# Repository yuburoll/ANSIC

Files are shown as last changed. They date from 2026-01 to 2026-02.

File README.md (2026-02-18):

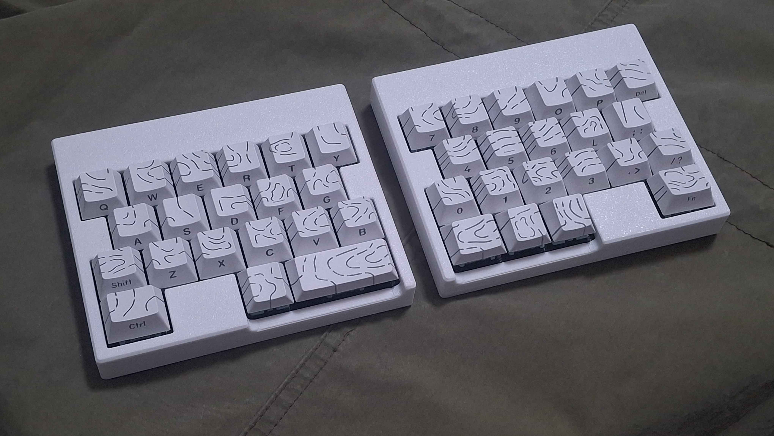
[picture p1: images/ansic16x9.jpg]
ansicImage


[한국어 설명은 여기에서 보실 수 있습니다](README_ko.md)

# ANSIC

uniform row staggered 40~42 key split keyboard under 100x100mm PCB

The name "ansic" is repose in Korean.

## Preparation

- 2x pro micro (Approx. 4-8$)

- 2x ansic PCB Boards (5 boards are 2$ on JLC w/o shipping cost)

- 1x printed case sets, 2 parts total (Approx. 6$ if you buy printed one on JLC. Use braced ones or 2mm ones for 3d print)

- 2x keyboard plates (Approx. 4~12$ which method you use: 3DP, FR4 fab, CNC, laser cut. etc...)

- 2x back plates (Approx. 6~18$ which method you use: 3DP, FR4 fab, CNC, laser cut. etc..)

- 42x diodes (Approx. 1$)

- 20x M2x6 screws, flathead (Approx. 1$)

- 2x PJ320A 1/8(3.5mm) TRRS connector (Approx. 1$)

- 2x 4x4x1.5mm surface mount tact switches (Approx. 1$)

- 1x 1/8(3.5mm) TRRS cable (Approx. 2$, may TRS cable can take the place.)

- 44x MX Hotswap Sockets (Approx. 5$) (or, use soldering version)

- 0~2x Plate Mounted 2u Keyboard Stabilizers (Approx. 1$ when cheap)

- 40~42x MX Keyswitches & Keycaps (Maybe this cost varies too much. 15$ on average)

Approx. 49-73$(w/o shipping cost) needed to build one.

for wireless build, you may additionally need:

- 2x "Wireless" promicro (eg. nrf52840)

- 2x 12c02 slide switch (very fragile, so handle with caution)

- 2x printed power switch part

- 2x xx2030 Li-po battery (eg. 902030) and socket(in 1.25)

## Default Keymap

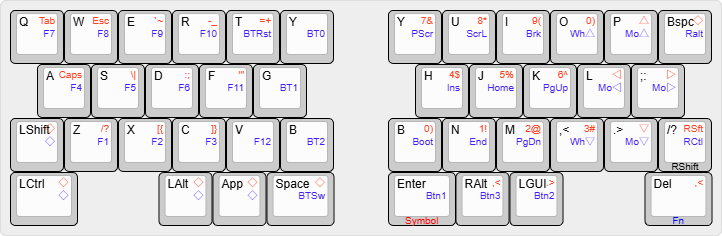
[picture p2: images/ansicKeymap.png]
ansicKeymap


Holding the key triggers front legend.

There are two more layers - Symbol, Fn - which can be noticed by the color legends. ◇ Means Transparent; which uses base keymap.

## Build Guides

work in progress. sorry! I uploaded images for buildguide at [images](images) folder.

also you may refer to the pictures below:

#### Wired

**You may flash the firmware first before the build.** It's hard to make dfu mode after the build.

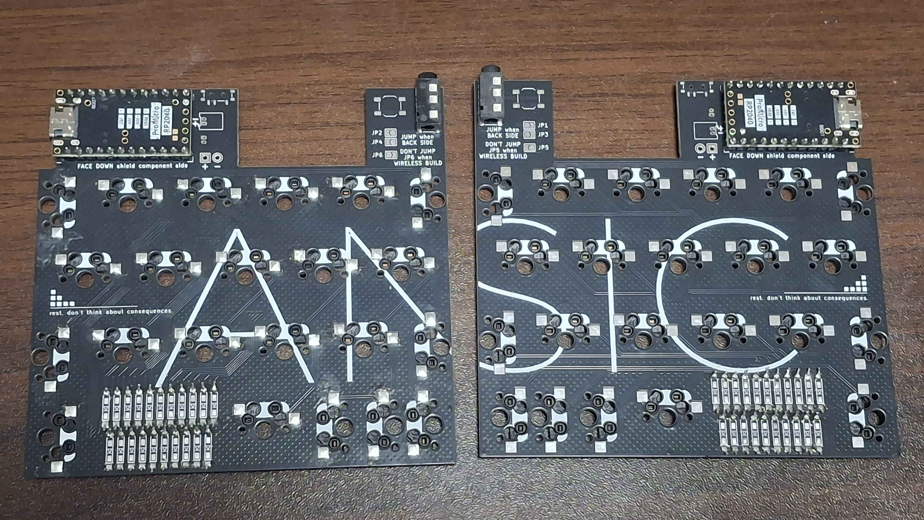
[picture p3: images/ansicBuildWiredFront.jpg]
WiredFront


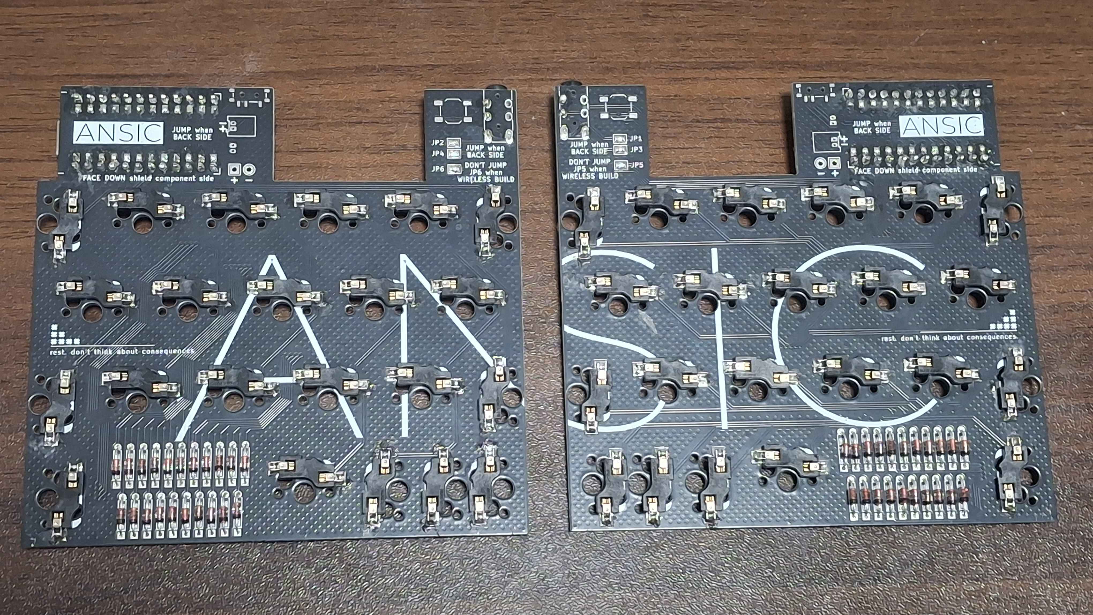
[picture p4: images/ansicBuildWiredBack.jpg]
WiredBack


#### Wireless

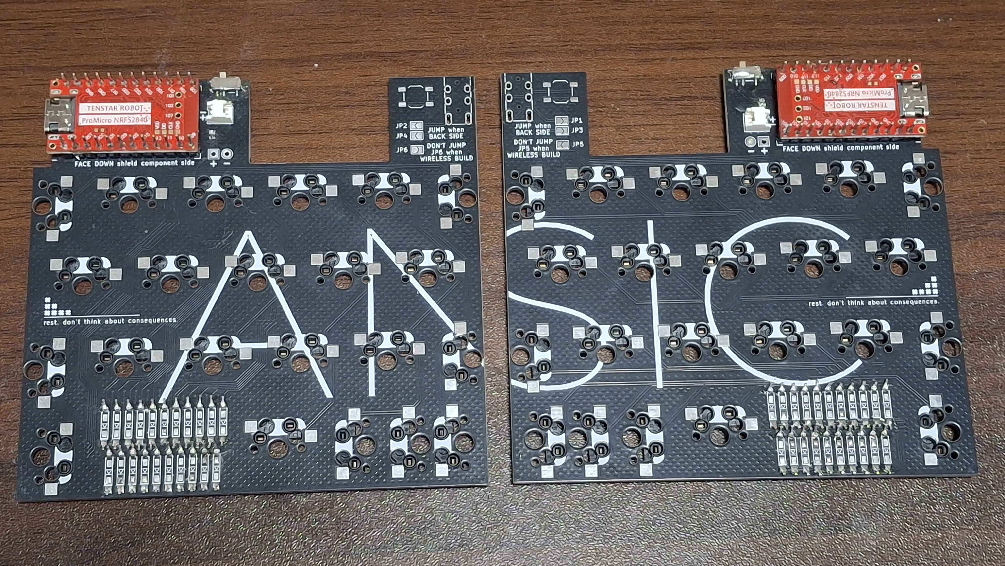
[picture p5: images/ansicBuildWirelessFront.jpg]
WirelessFront


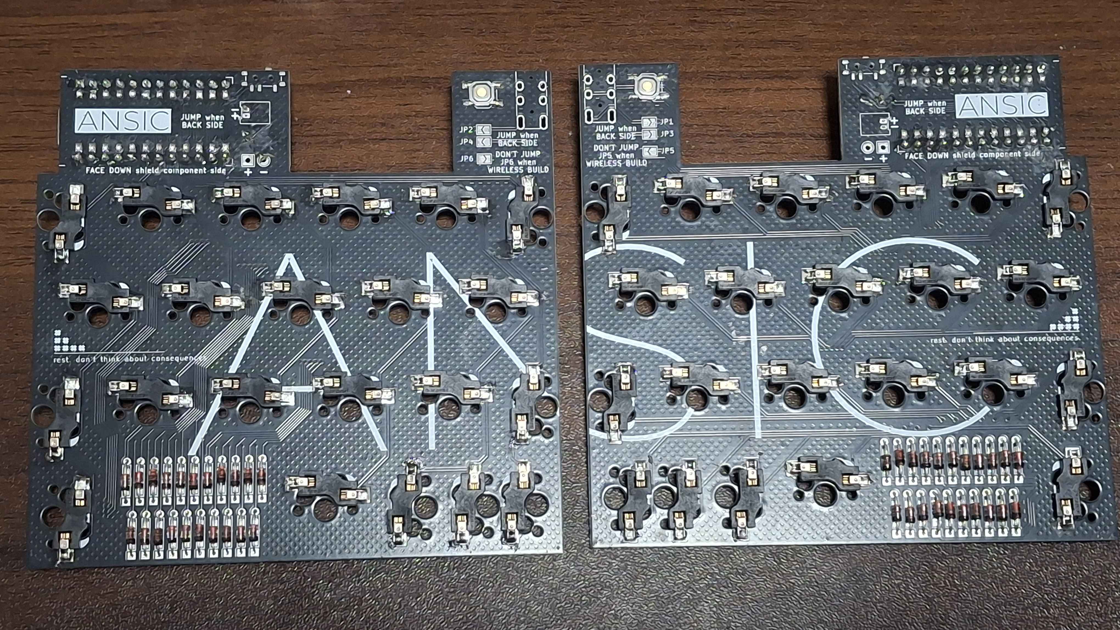
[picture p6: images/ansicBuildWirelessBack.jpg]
WirelessBack


## Note

On released version, they have merged thumb cluster based on SW21(outside thumb cluster).

(prototype) tagged versions are legacy file, which have merged thumb cluster based on SW20(middle thumb cluster). only the gerbers before Jan. 30, 2026 have those old schema.

Both Wired and Wireless version works well: proved by my two builds.

## Licenses

all codes follow MIT license.

all designs and the hardware board follow CC BY-SA 4.0 license.

If you want to make a commercial product, it would be appreciated if you sponsor some bucks for me.

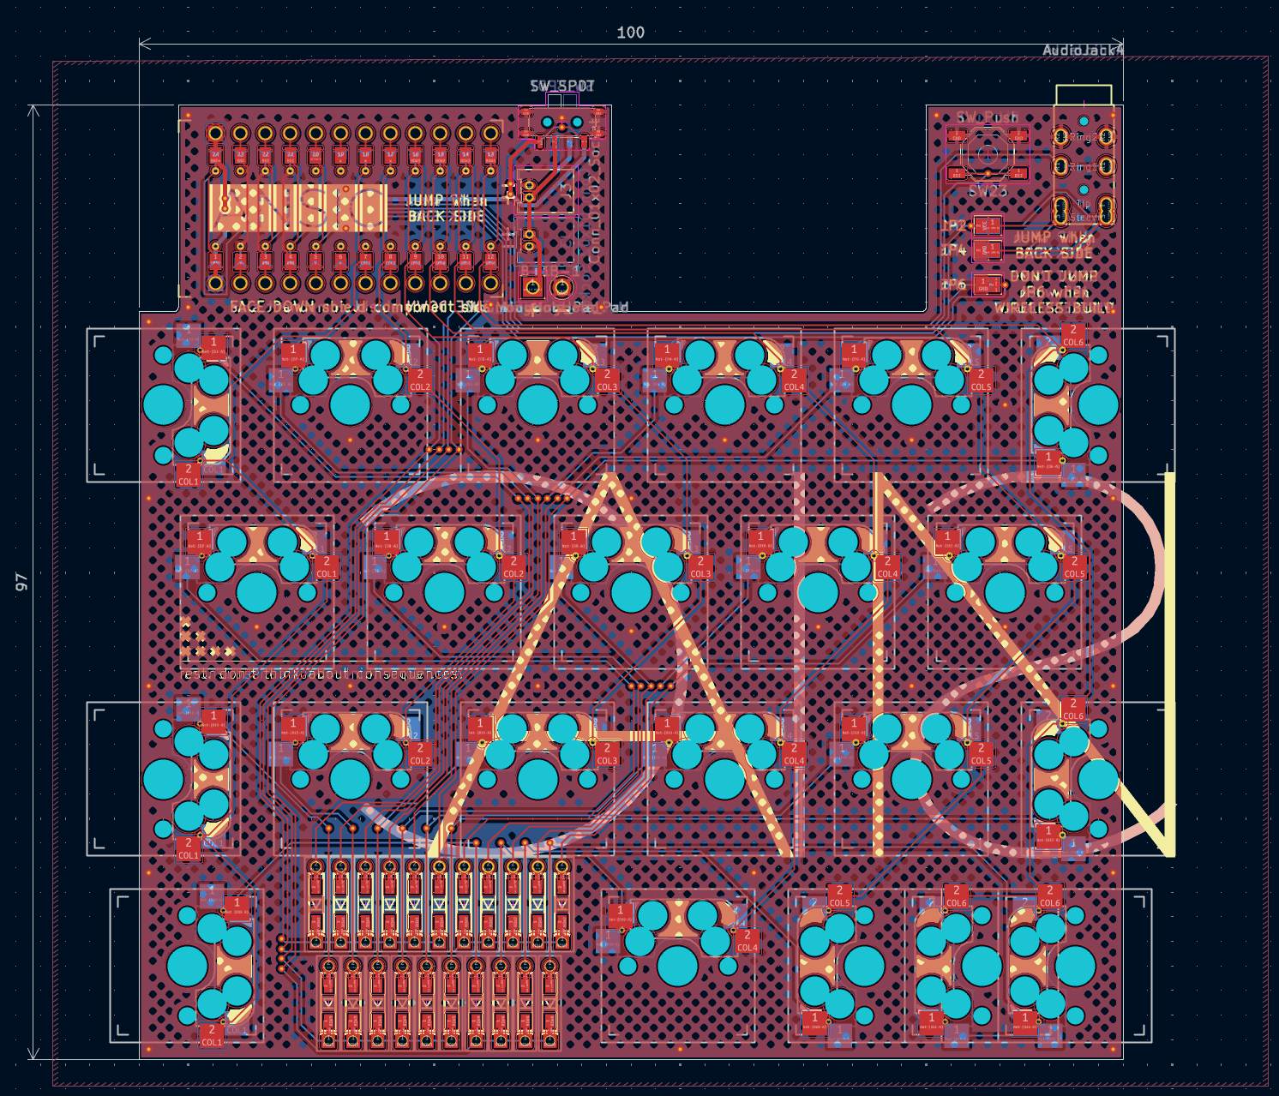
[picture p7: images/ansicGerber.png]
ansicGerber


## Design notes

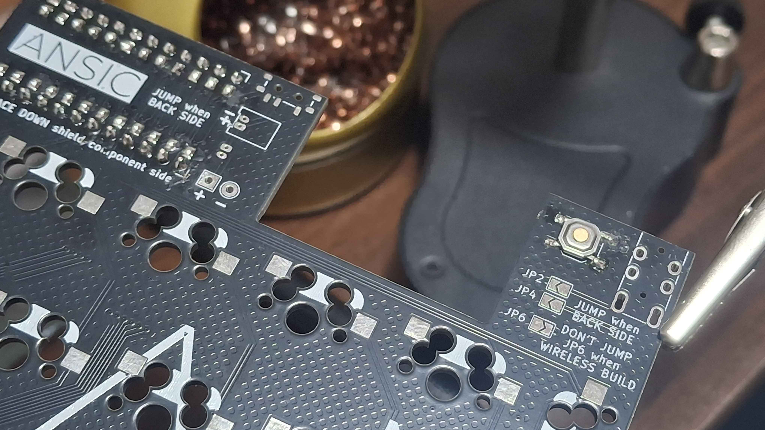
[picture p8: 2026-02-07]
images/ansicResetButton.jpg

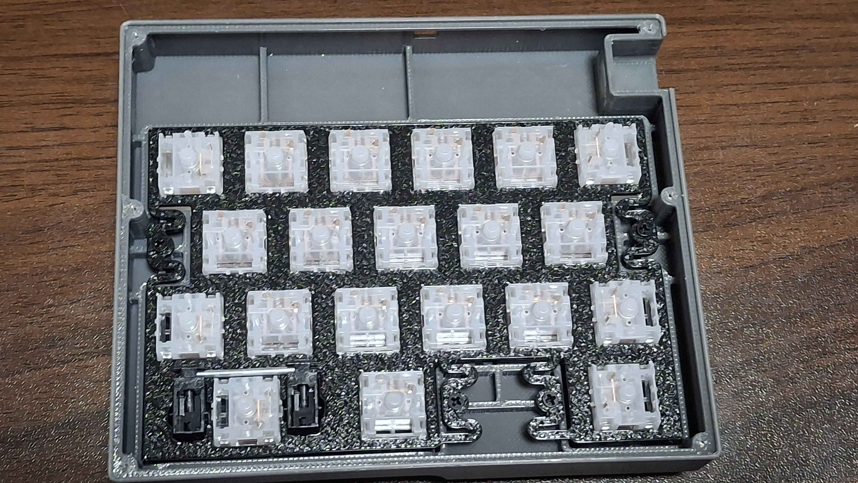
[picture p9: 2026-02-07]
images/ansicOrientation2.jpg

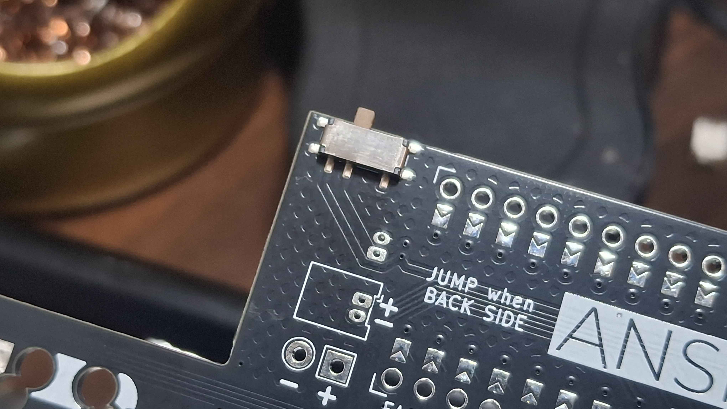
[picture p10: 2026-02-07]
images/ansicWirelessSwitch1.jpg

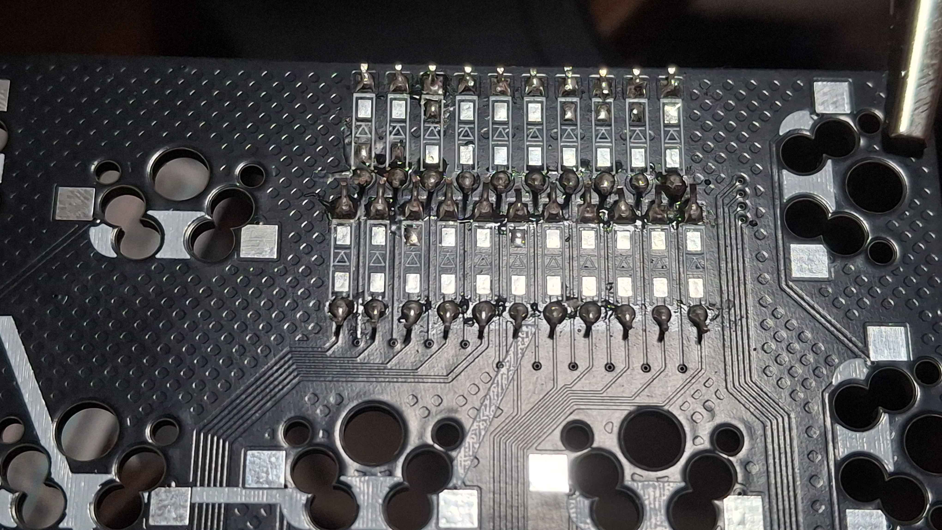
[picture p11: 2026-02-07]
images/ansicDiodes6.jpg

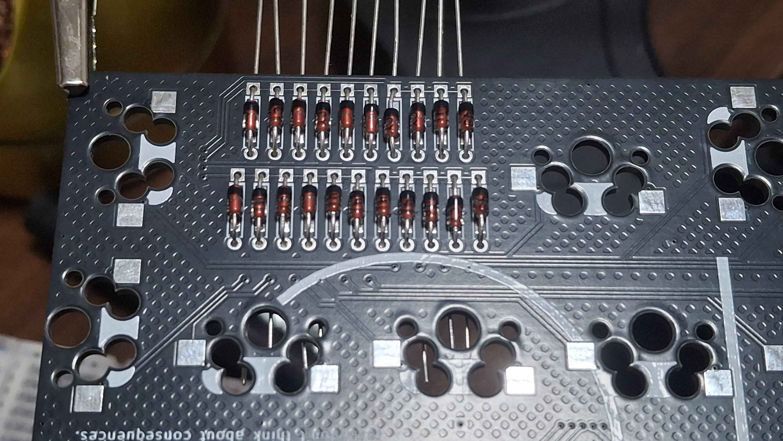
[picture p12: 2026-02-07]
images/ansicDiodes4.jpg

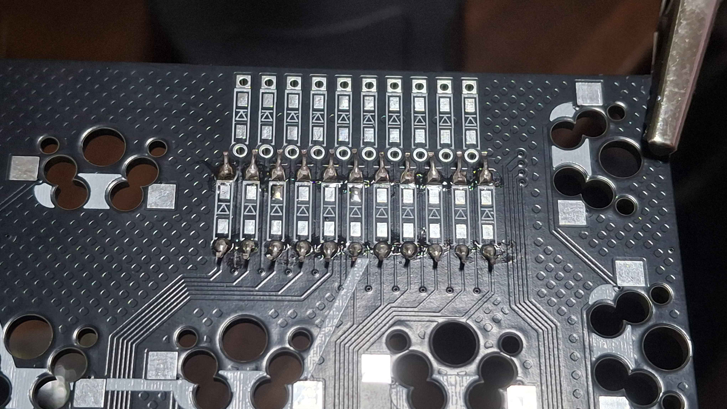
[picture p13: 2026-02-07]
images/ansicDiodes3.jpg

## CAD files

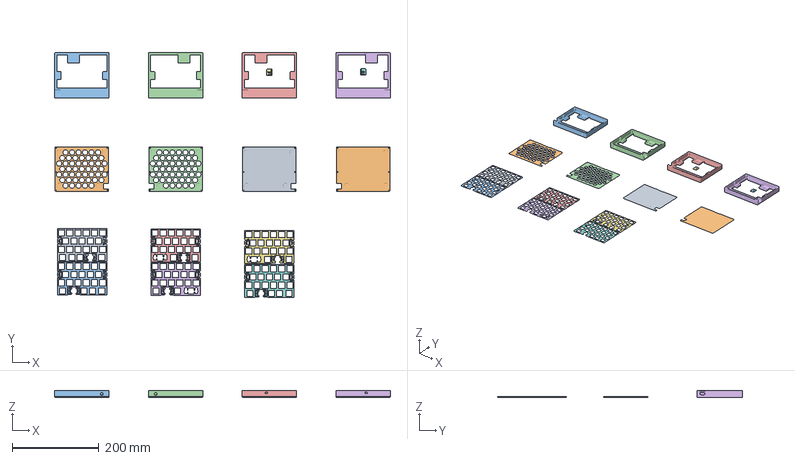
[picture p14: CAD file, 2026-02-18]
case/3mf/ansic2mm.3mf
774.0 x 564.9 x 15.5 mm
ansicPlate21.stl x 3
ansicBackMesh.stl x 2
ansicPlate20.stl x 3
ansicBack.stl x 2
ansicCase2mmWiredFDMBridgeL.stl
ansicCase2mmWiredFDMBridgeR.stl
ansicCase2mmWirelessFDMBridgeL.stl
ansicCase2mmWirelessFDMBridgeR.stl
ansicCase2mmWirelessSwitchSupport.stl x 2

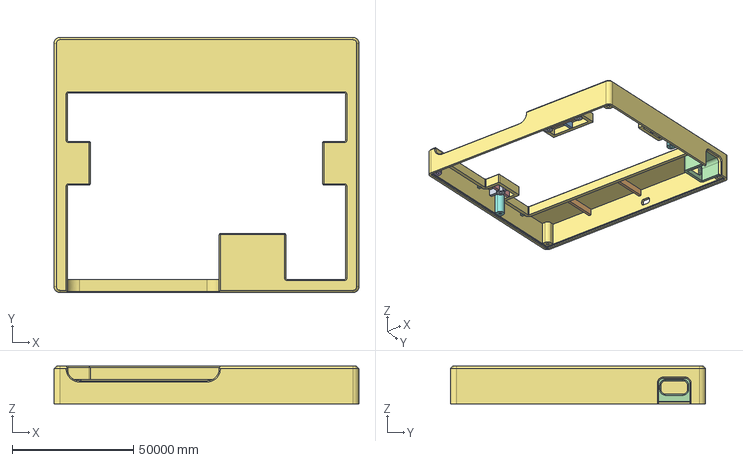
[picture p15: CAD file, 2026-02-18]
case/step/2mmThick/ansicCase2mmWirelessR.stp
126000.0 x 105500.0 x 15500.0 mm

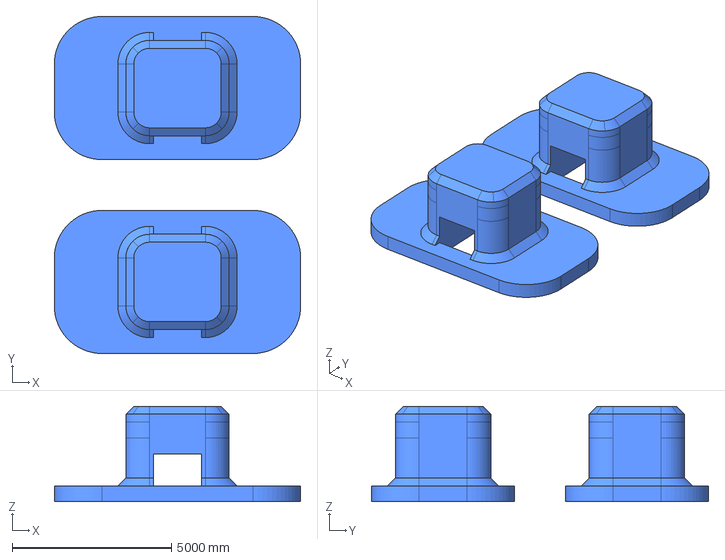
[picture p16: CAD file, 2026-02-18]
case/step/2mmThickSwitch/ansicCase2mmWirelessSwitch.stp
7750.0 x 10596.2 x 3000.0 mm

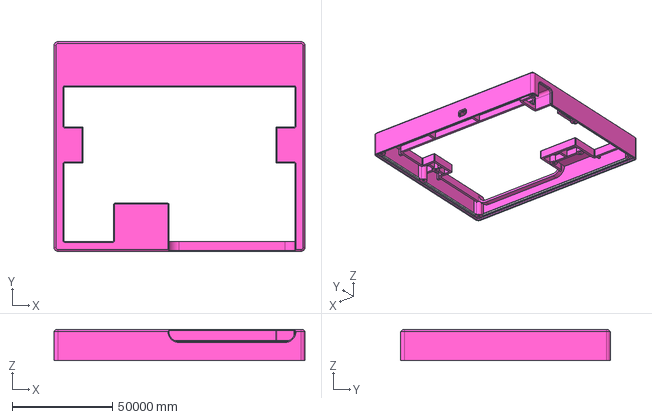
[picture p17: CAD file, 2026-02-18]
case/step/braced-for3DP/ansicCaseBraceWirelessL.stp
125000.0 x 104500.0 x 15500.0 mm

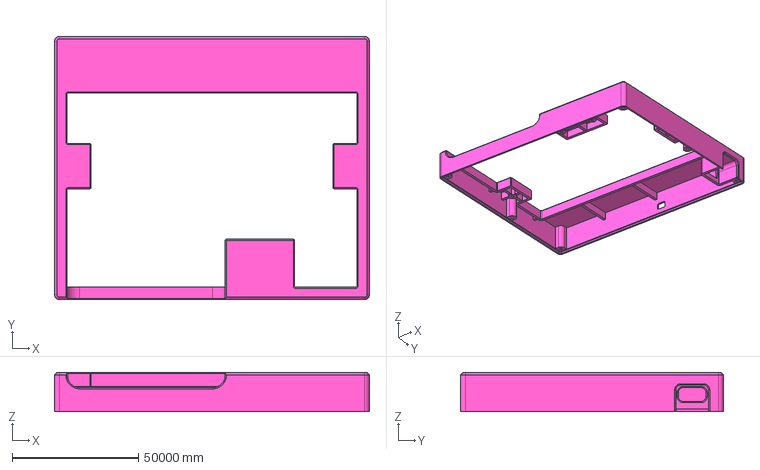
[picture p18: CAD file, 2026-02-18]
case/step/default/ansicCaseDefaultWirelessR.stp
125000.0 x 104500.0 x 15500.0 mm

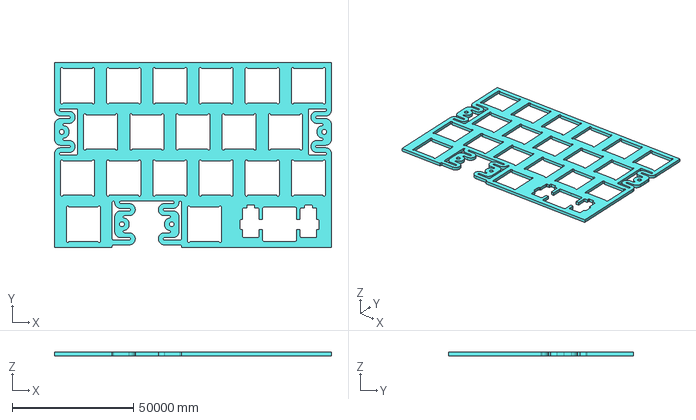
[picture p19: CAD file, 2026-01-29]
case/step/plates/ansicPlate20.stp
114000.0 x 76000.0 x 1500.0 mm

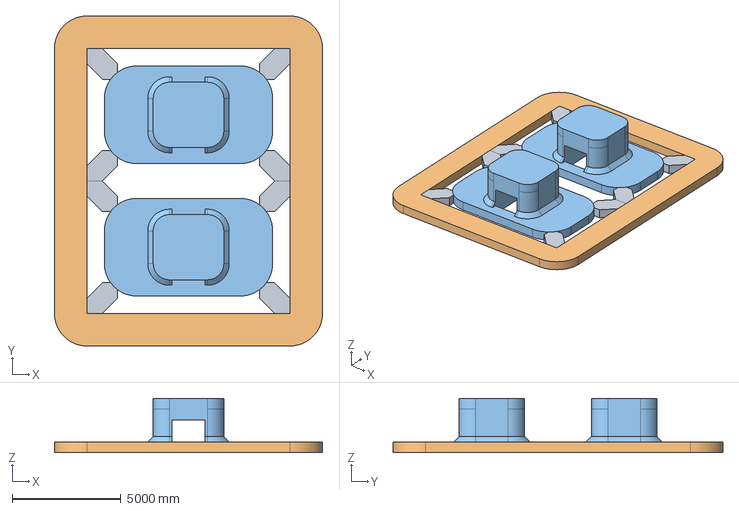
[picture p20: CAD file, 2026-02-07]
case/step/switch/ansicCaseWirelessSwitchSupport.stp
12346.2 x 15192.4 x 2500.0 mm

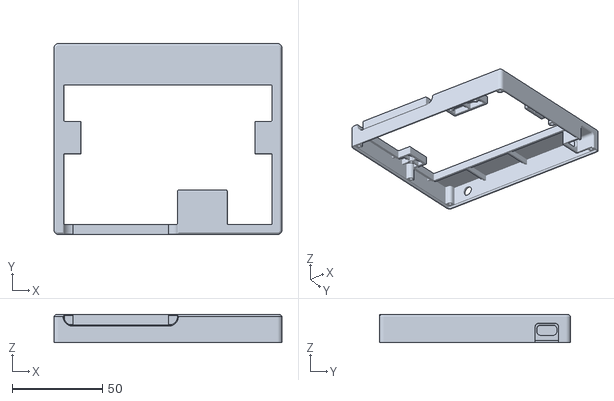
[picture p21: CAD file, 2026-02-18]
case/stl/2mmThickBridged-forFDM/ansicCase2mmWiredFDMBridgeR.stl
126.0 x 105.5 x 15.5

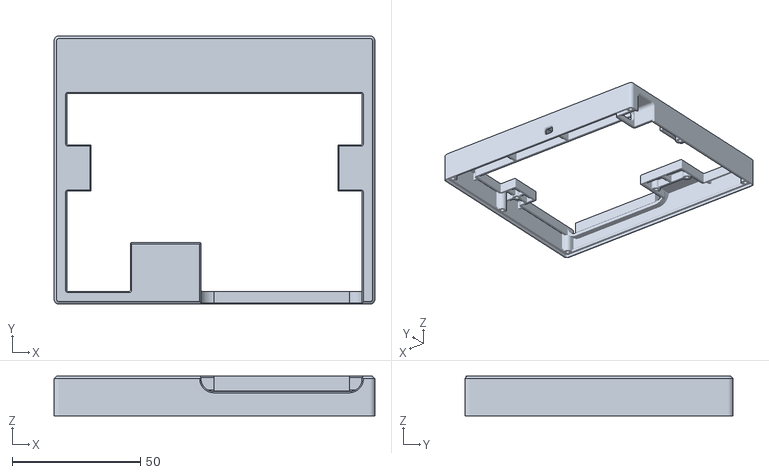
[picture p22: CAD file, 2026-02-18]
case/stl/bridged-forFDM/ansicCaseBraceWirelessFDMBridgeL.stl
125.0 x 104.5 x 15.5

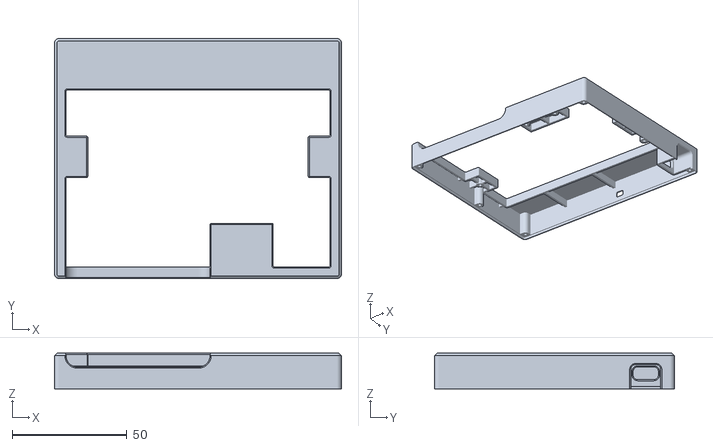
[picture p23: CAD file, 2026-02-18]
case/stl/default/ansicCaseWirelessR.stl
125.0 x 104.5 x 15.5

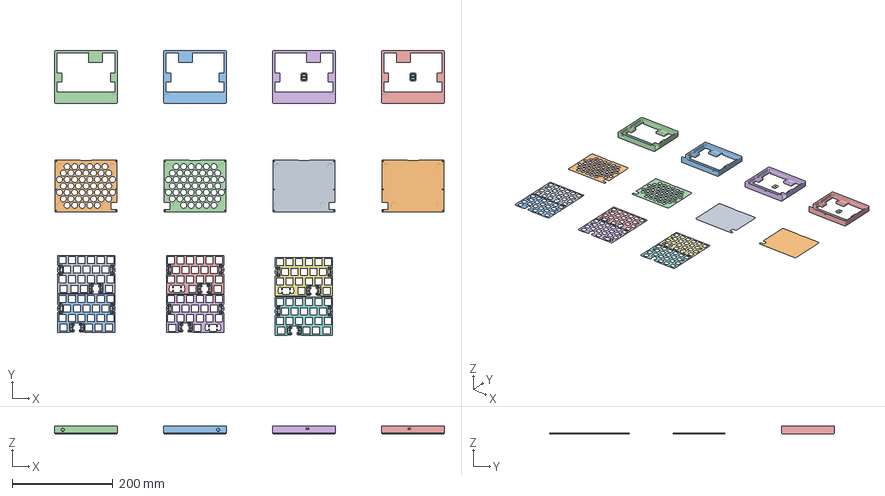
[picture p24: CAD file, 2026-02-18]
case/3mf/ansic.3mf
773.0 x 564.4 x 15.5 mm
ansicPlate21.stl x 3
ansicBackMesh.stl x 2
ansicPlate20.stl x 3
ansicBack.stl x 2
ansicCaseBraceWiredBridgeL.stl
ansicCaseBraceWiredBridgeR.stl
ansicCaseBraceWirelessBridgeL.stl
ansicCaseBraceWirelessBridgeR.stl
ansicCaseWirelessSwitchSupport.stl x 2

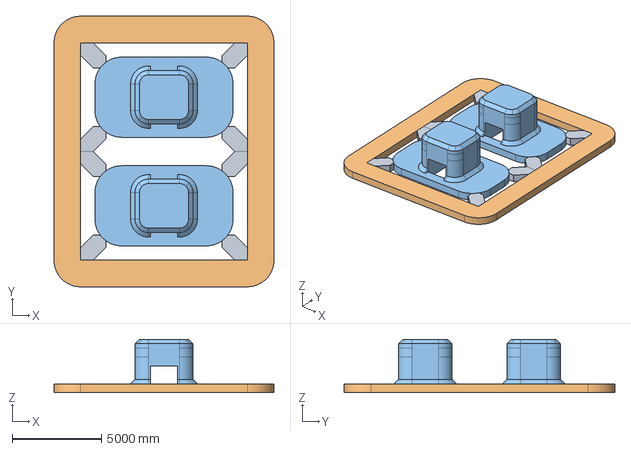
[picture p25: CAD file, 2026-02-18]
case/step/2mmThickSwitch/ansicCase2mmWirelessSwitchSupport.stp
12346.2 x 15192.4 x 3000.0 mm

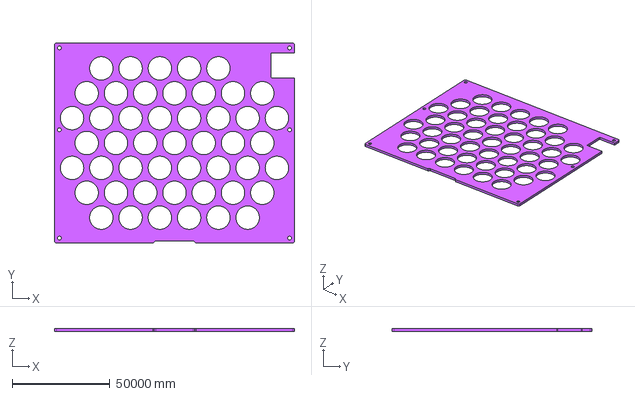
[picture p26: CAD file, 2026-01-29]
case/step/plates/ansicBackMeshR.stp
123000.0 x 102500.0 x 1500.0 mm

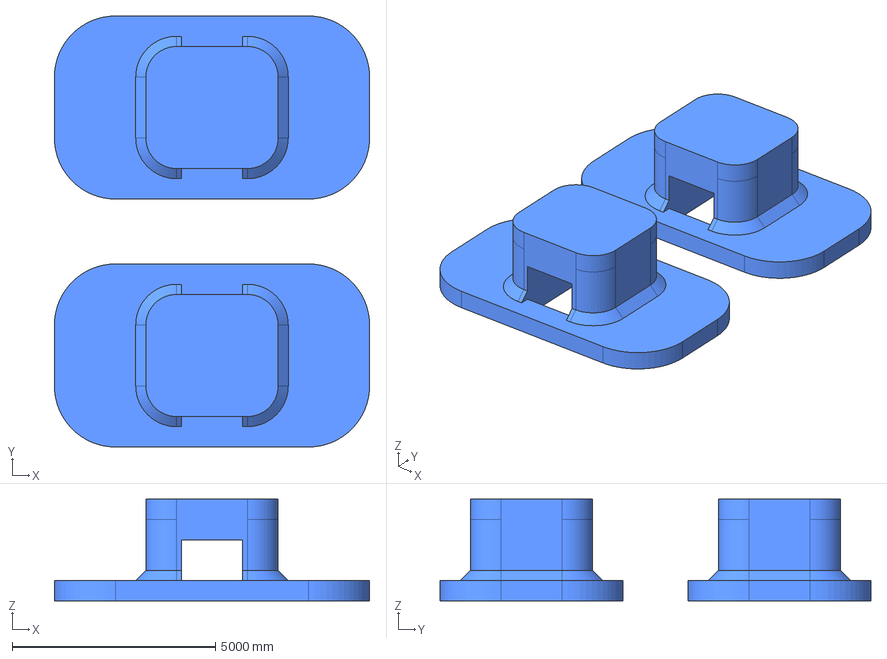
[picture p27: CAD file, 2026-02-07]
case/step/switch/ansicCaseWirelessSwitch.stp
7750.0 x 10596.2 x 2500.0 mm

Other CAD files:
case/step/2mmThick/ansicCase2mmWiredL.stp
case/step/braced-for3DP/ansicCaseBraceWiredR.stp
case/step/default/ansicCaseDefaultWiredR.stp
case/stl/2mmThickBridged-forFDM/ansicCase2mmWiredFDMBridgeL.stl
case/step/2mmThick/ansicCase2mmWiredR.stp
case/step/2mmThick/ansicCase2mmWirelessL.stp
case/step/braced-for3DP/ansicCaseBraceWiredL.stp
case/step/braced-for3DP/ansicCaseBraceWirelessR.stp
case/step/default/ansicCaseDefaultWiredL.stp
case/step/default/ansicCaseDefaultWirelessL.stp
case/step/plates/ansicBackDefaultL.stp
case/step/plates/ansicBackDefaultR.stp
case/step/plates/ansicBackMeshL.stp
case/step/plates/ansicPlate21.stp
case/stl/2mmThick/ansicCase2mmWiredL.stl
case/stl/2mmThick/ansicCase2mmWiredR.stl
case/stl/2mmThick/ansicCase2mmWirelessL.stl
case/stl/2mmThick/ansicCase2mmWirelessR.stl
case/stl/2mmThickBridged-forFDM/ansicCase2mmWirelessFDMBridgeL.stl
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

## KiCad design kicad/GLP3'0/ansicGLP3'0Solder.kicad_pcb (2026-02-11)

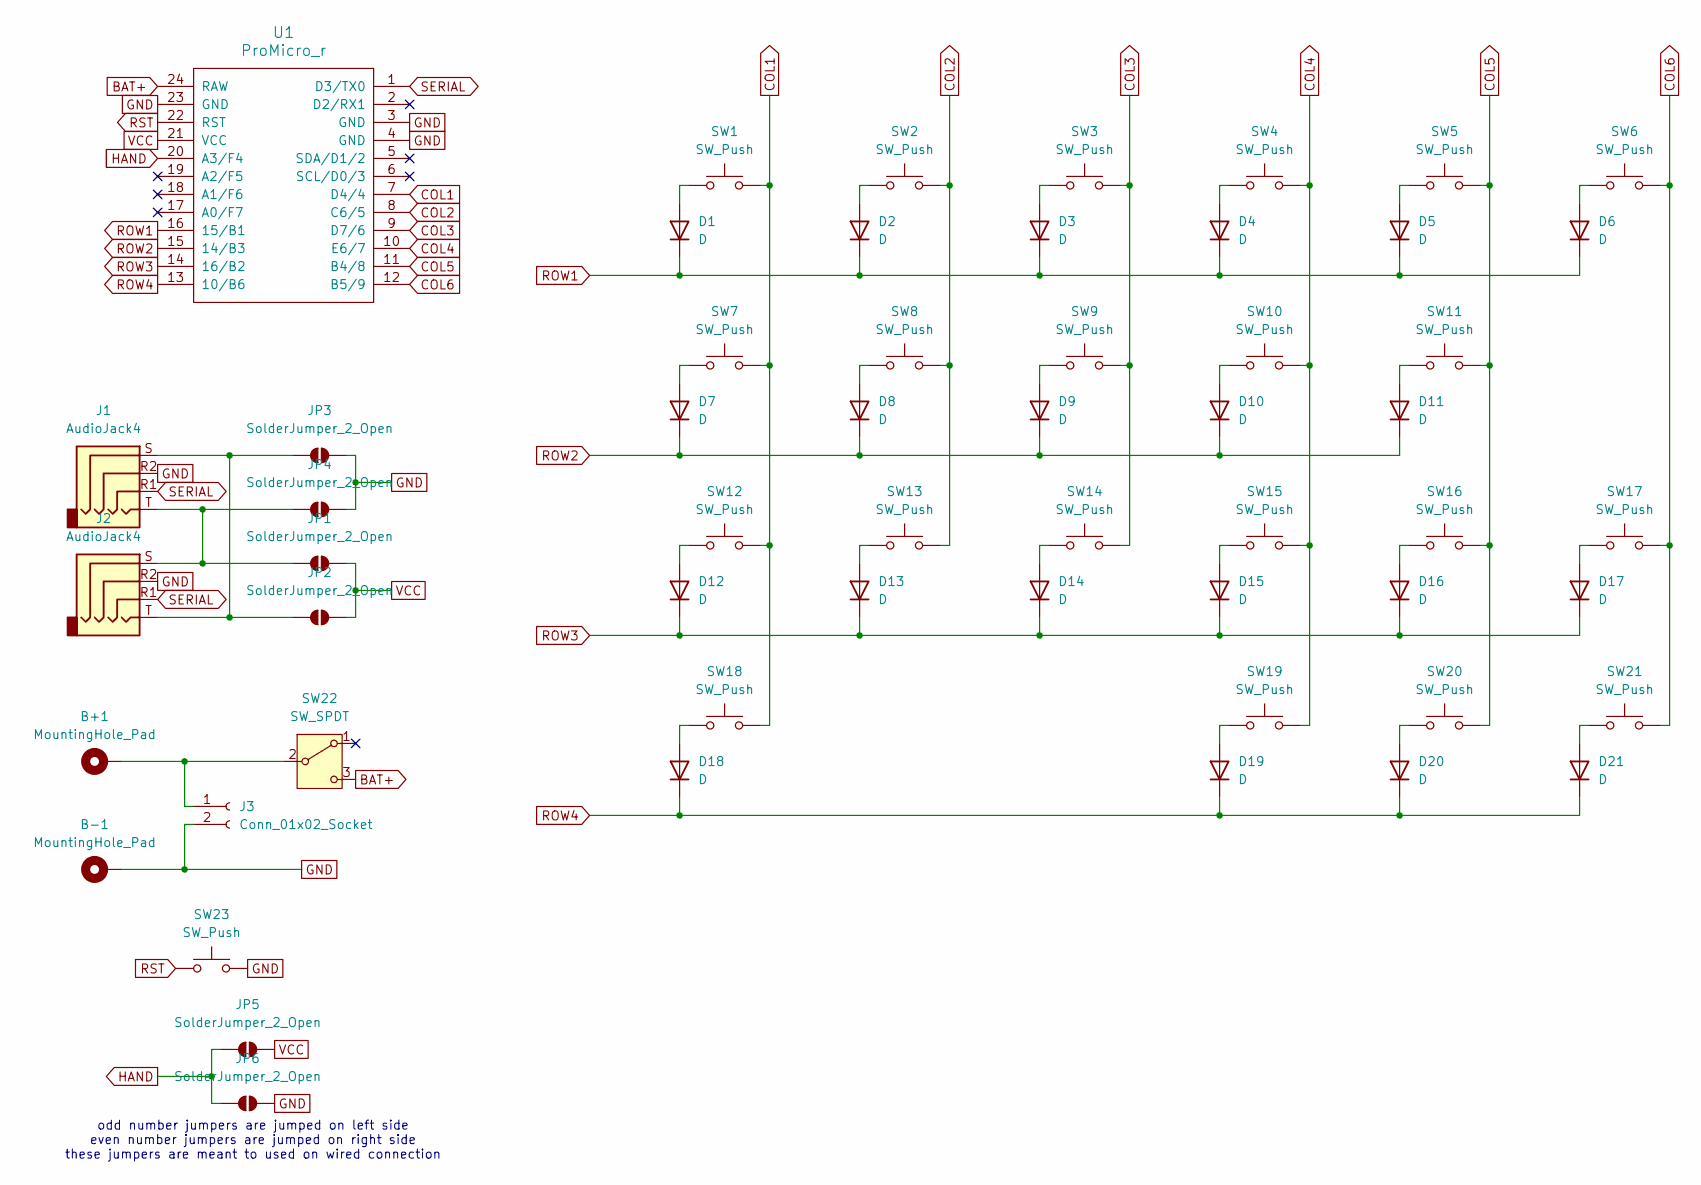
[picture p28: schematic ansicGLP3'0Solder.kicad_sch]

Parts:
B+1: MountingHole_Pad
B-1: MountingHole_Pad
D1, D2, D3, D4, D5, D6, D7, D8, D9, D10, D11, D12, D13, D14, D15, D16, D17, D18, D19, D20, D21: D
J1, J2: AudioJack4
J3: Conn_01x02_Socket
JP1, JP2, JP3, JP4, JP5, JP6: SolderJumper_2_Open
SW1, SW2, SW3, SW4, SW5, SW6, SW7, SW8, SW9, SW10, SW11, SW12, SW13, SW14, SW15, SW16, SW17, SW18, SW19, SW20, SW21, SW23: SW_Push
SW22: SW_SPDT
U1: ProMicro_r

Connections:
BAT+: SW22.3 (C), U1.24 (RAW); also elsewhere on the board
COL1: SW1.2, SW7.2, SW12.2, SW18.2, U1.7 (D4/4)
COL2: SW2.2, SW8.2, SW13.2, U1.8 (C6/5)
COL3: SW3.2, SW9.2, SW14.2, U1.9 (D7/6)
COL4: SW4.2, SW10.2, SW15.2, SW19.2, U1.10 (E6/7)
COL5: SW5.2, SW11.2, SW16.2, SW20.2, U1.11 (B4/8)
COL6: SW6.2, SW17.2, SW21.2, U1.12 (B5/9); also elsewhere on the board
GND: B-1.1, J1.R2, J2.R2, J3.2, JP3.2 (B), JP4.2 (B), JP6.1 (A), SW22.SH, SW23.2, U1.3 (GND), U1.4 (GND), U1.23 (GND); also elsewhere on the board
unnamed: D1.2 (A), SW1.1
unnamed: D2.2 (A), SW2.1
unnamed: D3.2 (A), SW3.1
unnamed: D4.2 (A), SW4.1
unnamed: D5.2 (A), SW5.1
unnamed: D6.2 (A), SW6.1
unnamed: D7.2 (A), SW7.1
unnamed: D8.2 (A), SW8.1
unnamed: D9.2 (A), SW9.1
unnamed: D10.2 (A), SW10.1
unnamed: D11.2 (A), SW11.1
unnamed: D12.2 (A), SW12.1
unnamed: D13.2 (A), SW13.1
unnamed: D14.2 (A), SW14.1
unnamed: D15.2 (A), SW15.1
unnamed: D16.2 (A), SW16.1
unnamed: D17.2 (A), SW17.1
unnamed: D18.2 (A), SW18.1
unnamed: D19.2 (A), SW19.1
unnamed: D20.2 (A), SW20.1
unnamed 28: D21.2 (A), SW21.1; also elsewhere on the board
unnamed 29: B+1.1, J3.1, SW22.2 (B); also elsewhere on the board
unnamed: J1.T, J2.S, JP1.1 (A), JP4.1 (A)
unnamed: J1.S, J2.T, JP2.1 (A), JP3.1 (A)
unnamed: JP5.2 (B), JP6.2 (B), U1.20 (A3/F4)
ROW1: D1.1 (K), D2.1 (K), D3.1 (K), D4.1 (K), D5.1 (K), D6.1 (K), U1.16 (15/B1)
ROW2: D7.1 (K), D8.1 (K), D9.1 (K), D10.1 (K), D11.1 (K), U1.15 (14/B3)
ROW3: D12.1 (K), D13.1 (K), D14.1 (K), D15.1 (K), D16.1 (K), D17.1 (K), U1.14 (16/B2)
ROW4: D18.1 (K), D19.1 (K), D20.1 (K), D21.1 (K), U1.13 (10/B6)
RST: SW23.1, U1.22 (RST); also elsewhere on the board
SERIAL: J1.R1, J2.R1, U1.1 (D3/TX0)
VCC: JP1.2 (B), JP2.2 (B), JP5.1 (A), U1.21 (VCC)

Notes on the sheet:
odd number jumpers are jumped on left side even number jumpers are jumped on right side these jumpers are meant to used on wired connection

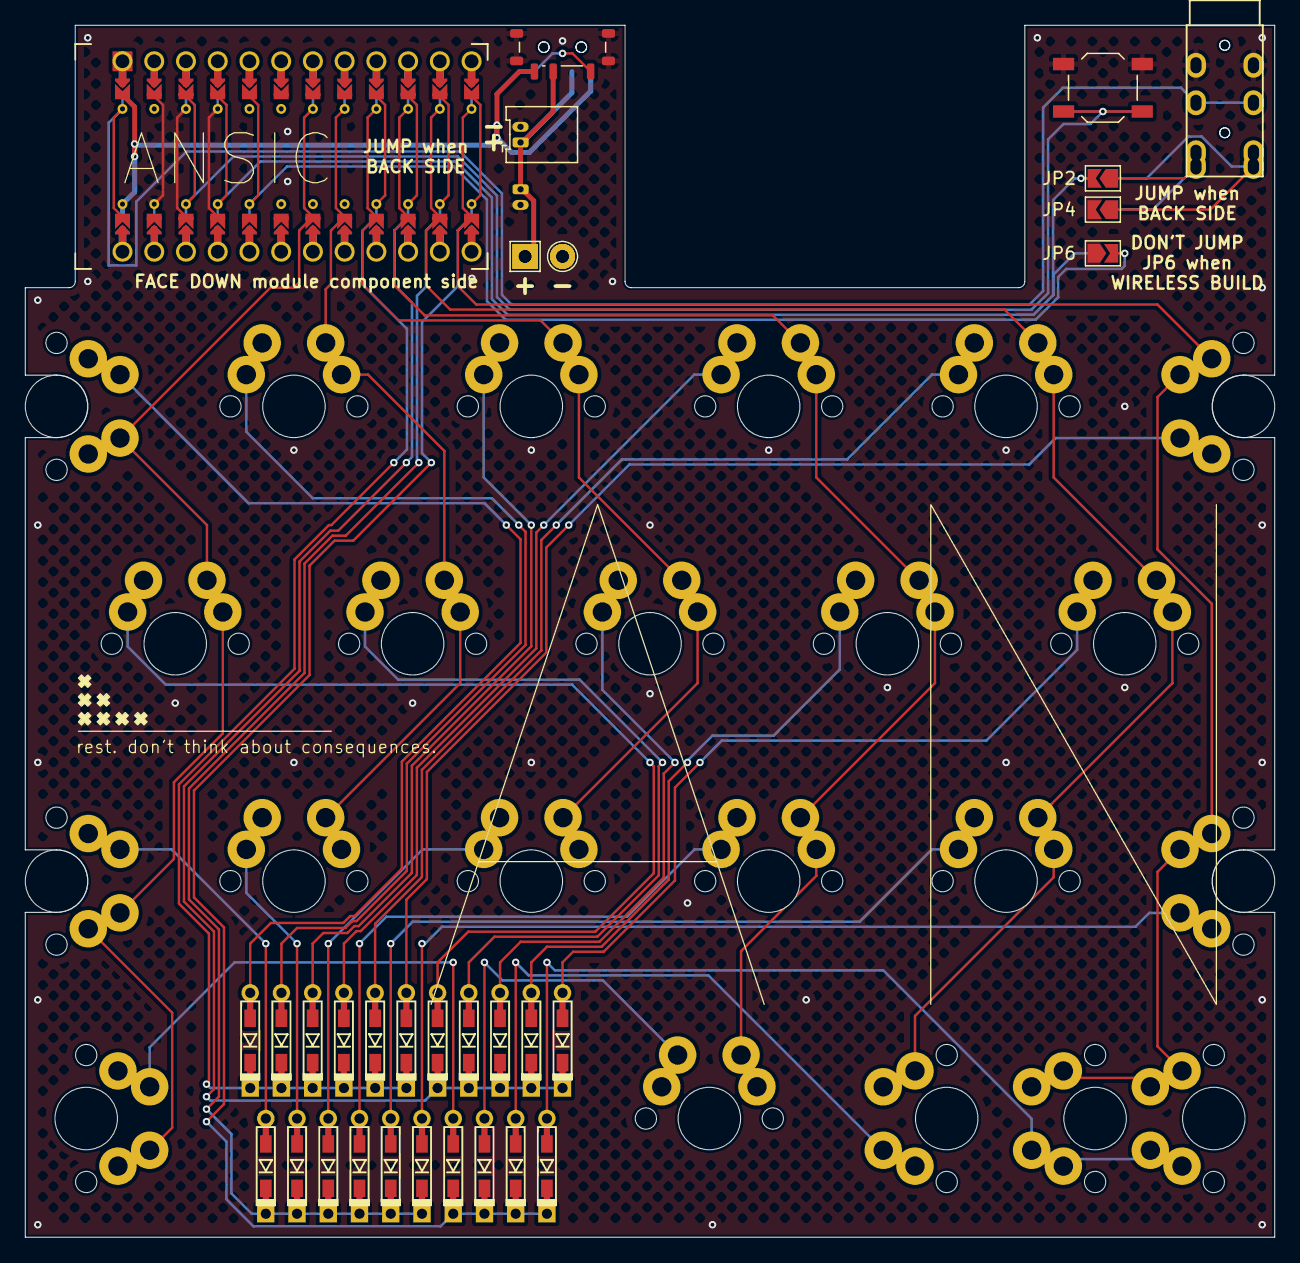
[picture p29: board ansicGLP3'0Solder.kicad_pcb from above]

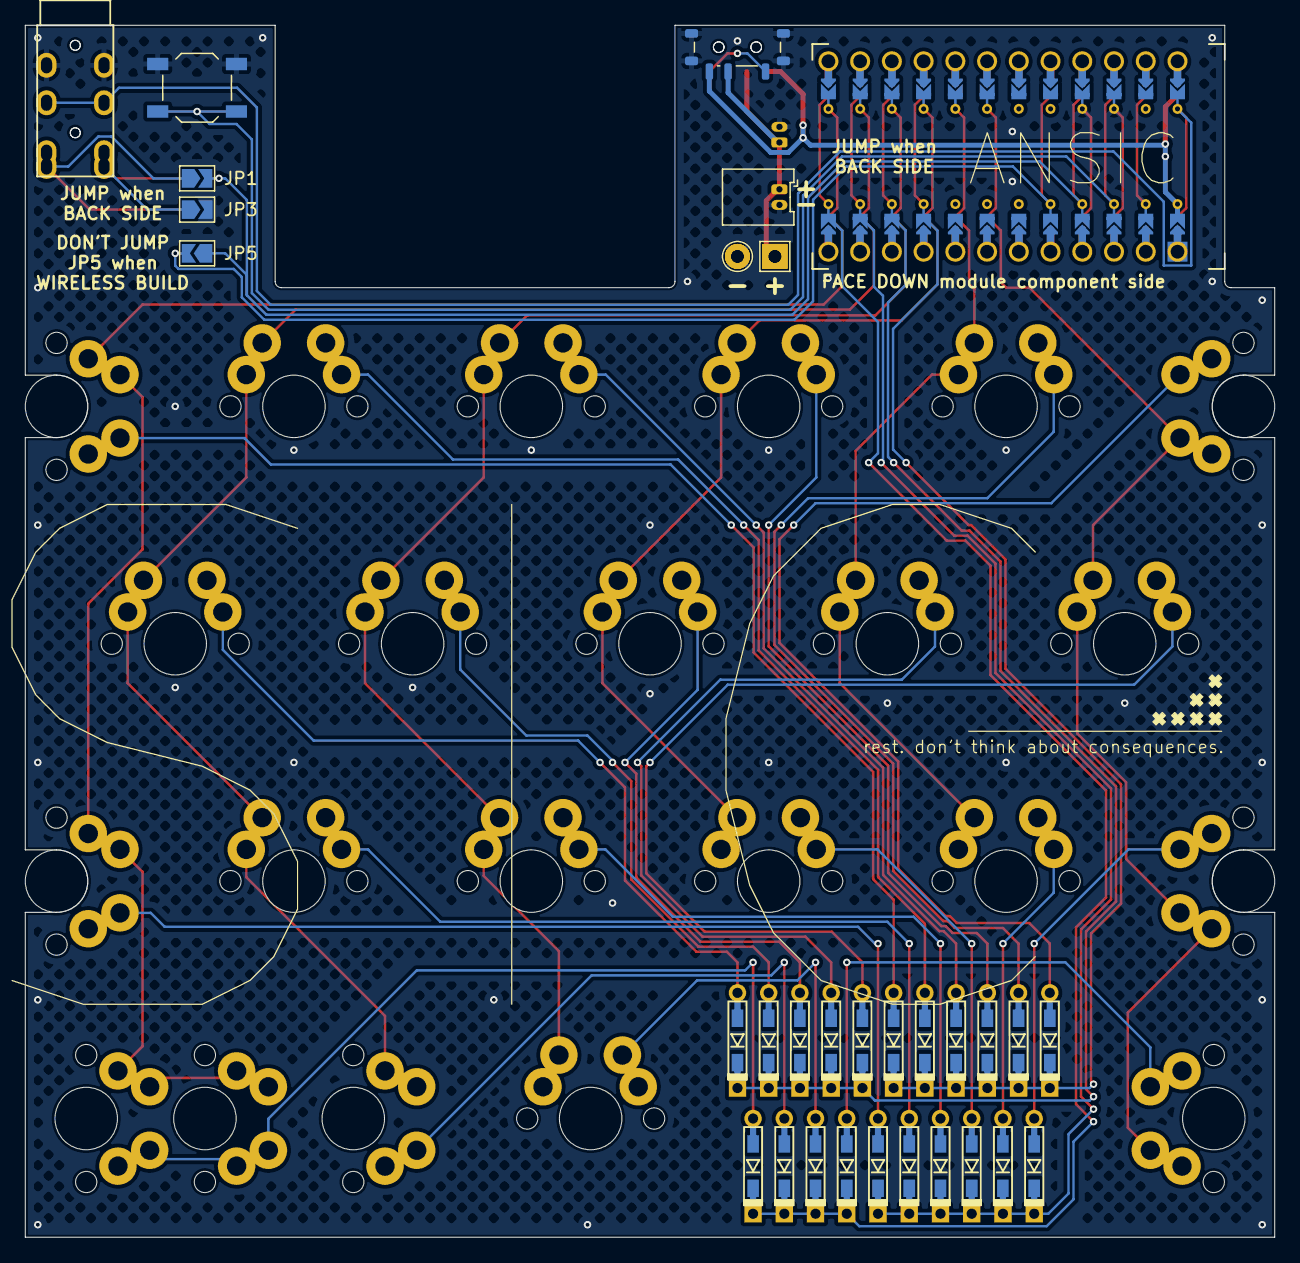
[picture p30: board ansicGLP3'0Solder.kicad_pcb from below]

Board: 2 copper layers, 100.0 x 97.0 mm, 62 parts (10 on the bottom side), 40 nets.

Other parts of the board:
B+1#2: MountingHole_Pad; TestPoint_THTPad_2.0x2.0mm_Drill1.0mm
B-1#2: MountingHole_Pad; TestPoint_THTPad_D2.0mm_Drill1.0mm
J3#2: Conn_01x02_Socket; Molex_PicoBlade_53048-0210_1x02_P1.25mm_Horizontal
SW21#2: SW_Push; MXGLP3'0_Mill-Max_FootprintPropertyFix
SW22#2: SW_SPDT; SW_SPDT_Shouhan_MSK12C02
SW23#2: SW_Push; SW_SPST_TL3342

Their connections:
BAT+: SW22#2.3 (C); also elsewhere on the board
COL6: SW21#2.2; also elsewhere on the board
GND: B-1#2.1, J3#2.2, SW22#2.SH, SW23#2.2; also elsewhere on the board
unnamed 28: SW21#2.1; also elsewhere on the board
unnamed 29: B+1#2.1, J3#2.1, SW22#2.2 (B); also elsewhere on the board
RST: SW23#2.1; also elsewhere on the board

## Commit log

2026-01-29 add license and readme
    [ansik.kicad_pcb]
2026-01-29 add plates for fab
    [ansikBackplate-B_Cu.gbr, ansikBackplate-B_Mask.gbr, ansikBackplate-B_Paste.gbr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]
2026-01-29 change name ansik to ansic
    [ansic-B_Cu.gbr, ansic-B_Mask.gbr, ansic-B_Paste.gbr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]
2026-01-29 update case data
    [ansicBackDefaultL.stl, ansicBackDefaultL.stp, ansicBackDefaultR.stl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]
2026-01-30 move case hole to upper 0.5mm
    [ansic.3mf, ansicCaseBraceWiredFDMBridgeL.stl, ansicCaseBraceWiredFDMBridgeR.stl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]
2026-01-30 upload wired firmware
2026-01-30 move merge thumb layout matrix
    [ansic-B_Cu.gbr, ansic-B_Mask.gbr, ansic-B_Paste.gbr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]
2026-01-30 add solder version
    [ansicSolder-B_Cu.gbr, ansicSolder-B_Mask.gbr, ansicSolder-B_Paste.gbr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]
2026-01-30 change gerber image
2026-01-31 fix confusing legend of silkscreen
    [ansic-B_Cu.gbr, ansic-B_Mask.gbr, ansic-B_Paste.gbr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]
2026-01-31 made bumpon place on backplate
    [ansicBackplate-B_Cu.gbr, ansicBackplate-B_Mask.gbr, ansicBackplate-B_Paste.gbr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]
2026-02-03 edited case chamfer for more soft texture
    [ansic.3mf, ansicCaseBraceWiredFDMBridgeL.stl, ansicCaseBraceWiredFDMBridgeR.stl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]
2026-02-03 add switch to wireless case and tweak thumb chamfer
    [ansic.3mf, ansicCaseBraceWiredFDMBridgeL.stl, ansicCaseBraceWiredFDMBridgeR.stl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]
2026-02-03 add tweaked keymap and made prototype vial only
2026-02-03 add water drain backplate
    [ansicBackplateDrain-B_Cu.gbr, ansicBackplateDrain-B_Mask.gbr, ansicBackplateDrain-B_Paste.gbr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]
2026-02-04 add bumpon and drain footprint
    [ansicBackplate-B_Cu.gbr, ansicBackplate-B_Mask.gbr, ansicBackplate-B_Paste.gbr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]
2026-02-04 edit for more readable schema
    [ansic.kicad_sch, ansicSolder.kicad_sch]
2026-02-07 fixed switch design for swapping
    [ansic.3mf, ansicCaseWirelessSwitch.stl, ansicCaseWirelessSwitch.stp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]
2026-02-07 add rmk wireless firmware
2026-02-07 thicken shield connectors to .6mm
    [ansic-B_Cu.gbr, ansic-B_Mask.gbr, ansic-B_Paste.gbr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]
2026-02-07 improve switch model
    [ansic.3mf, ansicCaseWirelessSwitch.stl, ansicCaseWirelessSwitch.stp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]
2026-02-11 kicad file for gateron lp 3.0
    [ansicGLP3'0.kicad_pcb, ansicGLP3'0.kicad_sch, ansicGLP3'0Solder.kicad_pcb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]
2026-02-12 update battery pin and name for rmk firmwares
2026-02-18 fix case inside error and make space for backplate
    [ansic.3mf, ansicCaseBraceWiredFDMBridgeL.stl, ansicCaseBraceWiredFDMBridgeR.stl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]
2026-02-18 add more thick version: 2mm
    [ansic2mm.3mf, ansicCase2mmWiredFDMBridgeL.stl, ansicCase2mmWiredFDMBridgeR.stl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]
2026-02-18 bigger bridge for fdm and additional readme notice
    [ansic2mm.3mf, ansicCase2mmWiredFDMBridgeL.stl, ansicCase2mmWiredFDMBridgeR.stl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]
